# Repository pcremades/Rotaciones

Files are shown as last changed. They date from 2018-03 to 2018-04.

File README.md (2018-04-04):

# Sistema para Rotaciones
Sistema disñado para el estudio de dinámica de rotación de cuerpos rígidos. El sistema consiste en un soporte sobre el que se puede montar el objeto que se quiere poner a rotar.
El soporte giratorio tiene un sistema de adquisición de datos incorporado que registra la velocidad angular instantánea y la velocidad angular máxima registrada.

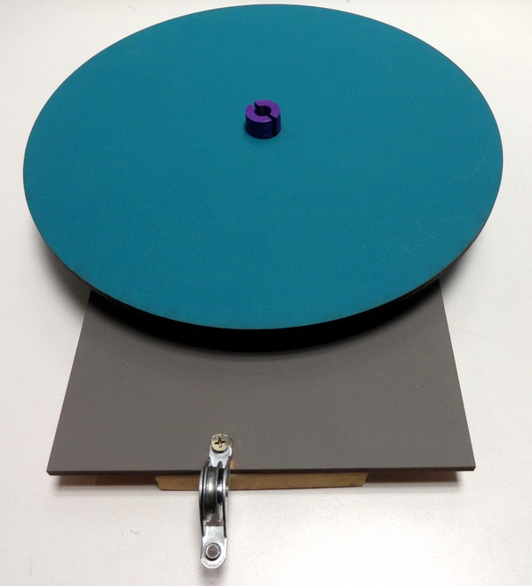
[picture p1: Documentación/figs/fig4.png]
Sistema de rotaciones con disco de 30cm


<br />Esta obra está bajo una <a rel="license" href="http://creativecommons.org/licenses/by-nc/4.0/">Licencia Creative Commons Atribución-NoComercial 4.0 Internacional</a>.

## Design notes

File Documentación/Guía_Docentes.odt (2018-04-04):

# Riel de Aire: guía para docentes

## Materiales

- Sistema para estudio de rotaciones con sistema de adquisición de datos
- Disco de madera de 30cm de diámetro
- PC
- Hilo
- Porta-pesas

## Armado

Coloque el sistema de rotaciones sobre la mesa, de manera tal que el extremo que tiene la polea quede fuera de la mesa.

Pase el hilo por cualquiera de los orificios practicados en el soporte plástico y fije con un trozo de cinta adhesiva la punta del mismo al soporte. El hilo deberá quedar enhebrado de forma tal que pueda enrollarse en la polea.

Pase el hilo por la roldana que se encuentra sobre el borde del equipo de rotaciones de modo que éste quede colgando. Ate el porta-pesas en ese extremo.

Coloque el disco de madera sobre el soporte y agregue peso al porta-pesas (aproximadamente 30g).

Verifique que el hilo se enrolle fácilmente en la polea al girar el disco, y que el peso adicionado sea suficiente para poner la rueda en movimiento una vez que se lo libera.

## Desarrollo

Dibuje para los estudiantes un esquema del sistema a analizar como el que se muestra en la figura 1.

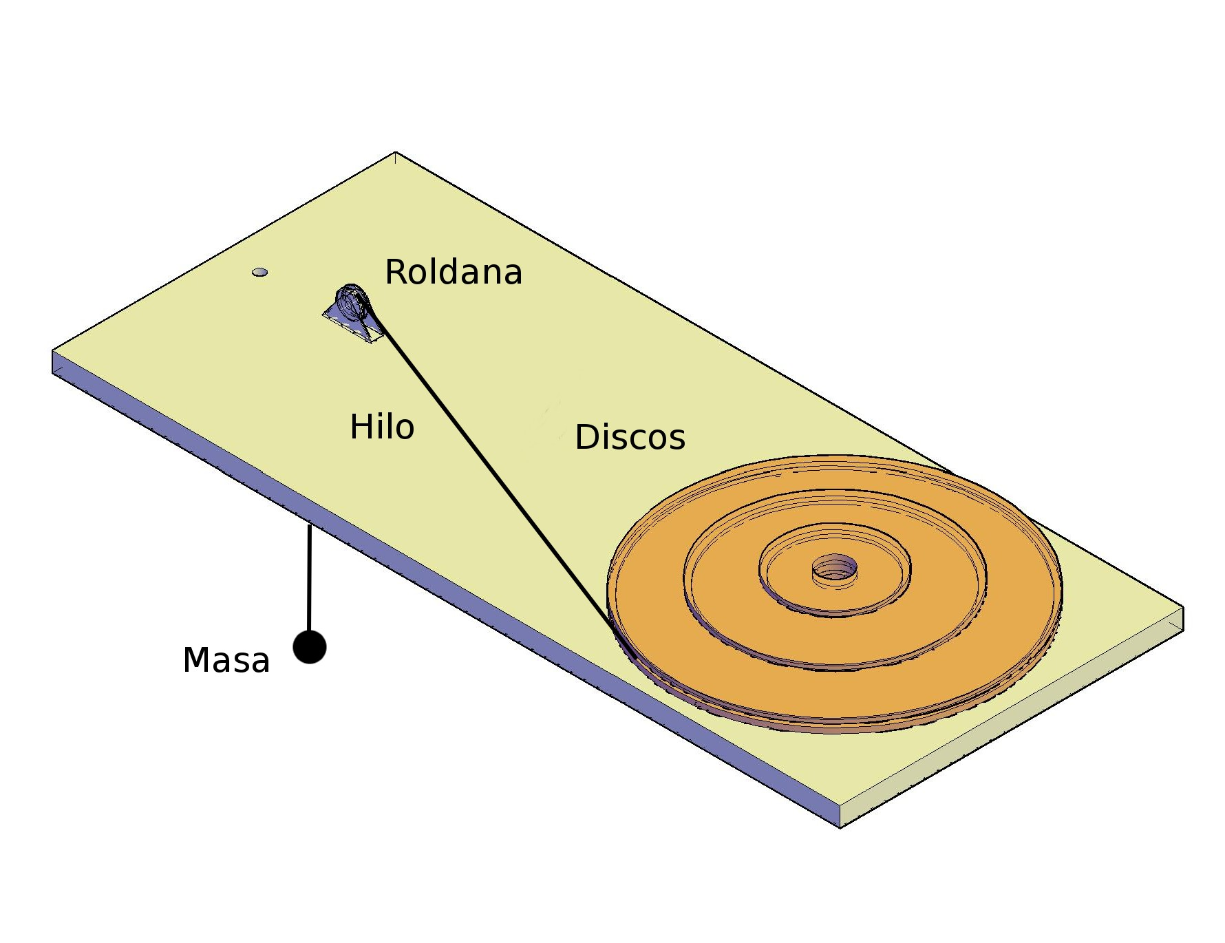
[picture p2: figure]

Fig. 1. Esquema del sistema bajo estudio.

Pida a los estudiantes que encuentren una expresión para la velocidad angular máxima del disco cuando el contrapeso (masa m) ha caído una altura h. Podrán hacer un análisis dinámico o plantear conservación de la energía mecánica. En el caso de hacer el análisis mediante consideraciones dinámicas, pida a los estudiantes que realicen el diagrama de cuerpo libre de los dos cuerpos. La expresión para la velocidad final está dada por la ecuación 1.

%omega_f = sqrt{ {2.(m.g . h - %tau_r. h over r)} over {I + m.r^2} }
(1)

donde I es el momento de inercia del disco, r es el radio de la polea sobre la que se enrolla el hilo, y τr es el torque de rozamiento, dado por el fabricante según la siguiente expresión:

τ=0.5*%mu*P*d (2)

donde:

τ : momento de fricción

μ : coeficiente de fricción constante del rodamiento: 0.002

P : carga dinámica equivalente: P=0.1*C

C : capacidad de carga del rodamiento: 2.6kN

d : diámetro interno del rodamiento: 8mm

Luego deberán medir las masas y la altura h para calcular la velocidad angular final. Además deberán calcular el intervalo de confianza de la velocidad final teórica mediante propagación de errores (ecuación 3):

%DELTA %omega_f = sqrt{ sum { left ( {partial %omega_f} over {partial x_i} right )^2 . %DELTA x_i^2 } } = sqrt{ left ( {partial %omega_f} over {partial m} . %DELTA m right)^2 +
left ( {partial %omega_f} over {partial I} . %DELTA I right)^2 +
left ( {partial %omega_f} over {partial h} . %DELTA h right)^2}
(3)

donde los errores estarán dados por los instrumentos utilizados para determinar m y h. En el caso del momento de inercia del disco, ésta es una medida indirecta, por lo que su incertidumbre debe determinarse también mediante propagación de errores a partir de los errores en la masa del disco y el radio.

Una vez establecido el intervalo de confianza de la estimación de ωf, deberán hacer el experimento y hallar el valor experimental de la velocidad angular final. Deberán realizar varias repeticiones del experimento y encontrar el valor medio y la desviación estándar y comparar los intervalos de confianza teórico y experimental y concluir.

El sistema de adquisición de datos registra la velocidad angular instantánea y la velocidad angular máxima.

## Sugerencias

Muestre a los estudiantes que la velocidad angular máxima no depende de la polea que elijan, siempre que la masa y la longitud del hilo sea la misma. Demuestre realizando el análisis a partir de la conservación de la energía mecánica.

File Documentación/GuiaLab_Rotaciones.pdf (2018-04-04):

### Laboratorio 5

### Rotación de cuerpos rígidos

Objetivo
Comprobar la validez de la ecuación:
EMi + WNC = EMf | (Ec.1)
en un sistema de cuerpos rígidos en rotación.
Donde,
EMi : Es la Energía Mecánica inicial del sistema,
WNC : Es el trabajo hecho por Fuerzas No Conservativas sobre el sistema, y
EMf : Es la Energía Mecánica final del sistema,

Materiales y métodos
El equipo consiste en un soporte rotativo con bajo rozamiento, pero no despreciable, y con sistema de adquisición de datos incorporado (Figura 1). Sobre el soporte se pueden montar discos o barras rígidas.
El soporte tiene 2 poleas con distintos diámetros. Se conecta mediante un hilo cualquiera de las poleas del soporte a una masa que cuelga de una roldana. De esta manera la tensión del hilo ejerce un torque sobre el sistema de discos que le imprimirá una aceleración angular.
Cuando el sistema se libera del reposo la masa suspendida comenzará a descender recorriendo una distancia conocida hasta que finalmente llega al extremo inferior del recorrido.
El equipo incluye un sistema de adquisición de datos que permite medir la velocidad angular instantánea de los discos y registra la velocidad angular máxima alcanzada.

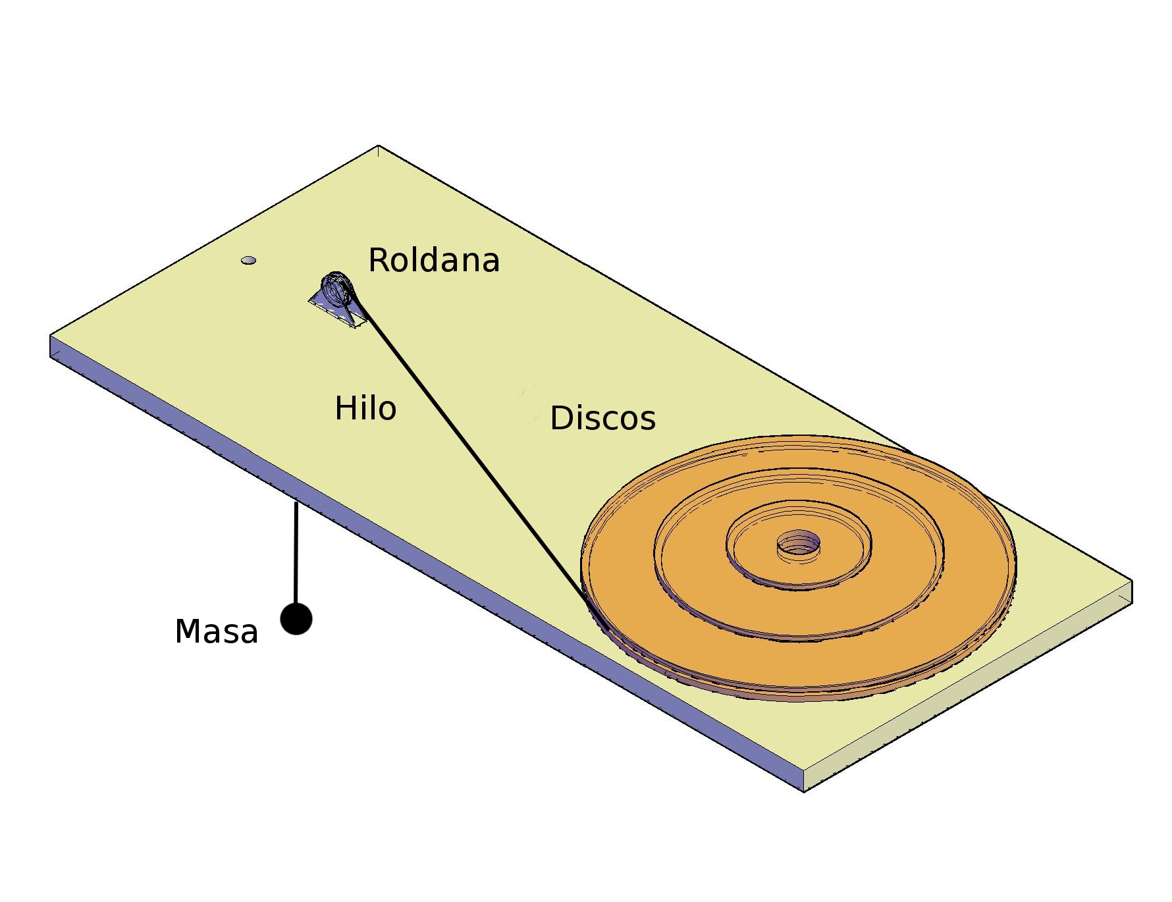
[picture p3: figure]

Figura 1: esquema del sistema de rotaciones.

Descripción de la experiencia

Deberá predecir la velocidad angular que alcanza el sistema de discos luego de que el torque de la tensión ha actuado sobre él hasta el momento en que la masa llega a la posición final.

Consideraciones sobre el Torque de la fricción:
Dado que no es posible despreciar la fricción en el eje del sistema de discos, deberá incluir el trabajo que hace esta fuerza de fricción en su análisis. Para ello, el fabricante del rodamiento proporciona toda la información necesaria. El torque de fricción viene determinado por la expresión:

τ=0.5∗μ∗P∗d
donde:
τ : momento de fricción
μ : coeficiente de fricción constante del rodamiento: 0.0013 P : carga dinámica equivalente: P=0.1∗C
C : capacidad de carga del rodamiento: 10kN
d : diámetro interno del rodamiento: 10mm

Consideraciones sobre el momento de Inercia:
Necesitará determinar una expresión para el momento de Inercia del cuerpo rígido que coloque en el soporte. Para ello, debe considerar la masa del soporte también.
1) A partir de la Ec. 1 encuentre una expresión para la velocidad angular máxima que alcanzará el sistema de discos y determine las variables que intervienen.
2) Mida en forma directa las variables que intervienen en su medición indirecta de la velocidad angular máxima.
3) Calcule la velocidad angular máxima que alcanzará el sistema.
4) Mida la velocidad angular máxima del sistema con la PC.
5) Calcule el intervalo de confianza de la predicción mediante teoría de propagación de errores.
6) Estime cuán significativo es el efecto del rozamiento.
7) Determine el intervalo de confianza de las medición que hizo de la velocidad angular máxima.
8) Compare ambas mediciones y concluya si son coincidentes.

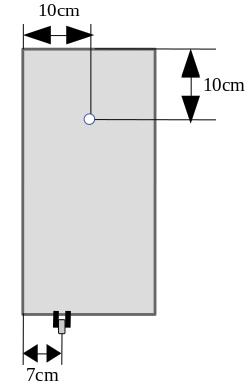
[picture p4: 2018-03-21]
Imagenes/fig1.jpg

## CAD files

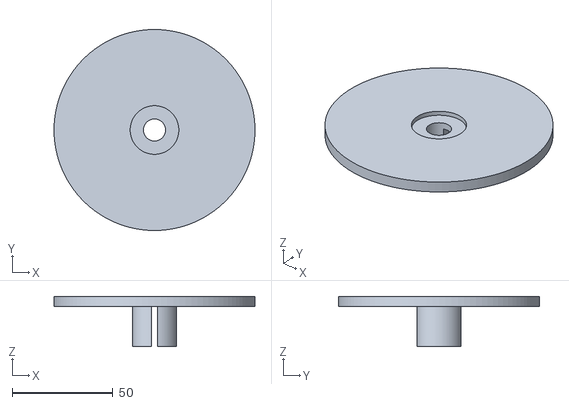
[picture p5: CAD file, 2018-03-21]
Hardware/plataforma rotacion.stl
100.0 x 100.0 x 25.0

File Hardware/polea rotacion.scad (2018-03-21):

include<UGroovePulley.scad>
$fn=100;

rotate([180,0,0])
translate([0,0,5])
//render_part(1);
render_part(2);

module render_part(part_to_render) {
	if (part_to_render == 1) poleas();
	if (part_to_render == 2) plataforma();
}

module poleas(){

//GroovePulley(radius, outer_radius, thickness, groove_radius, circles)
UGroovePulley(12.5,40,5,1,0);
translate([0,0,5])
UGroovePulley(12.5,20,5,1,0);
}

module plataforma(){
translate([0,0,-5])
difference(){
//Disco plataforma
cylinder(5,50,50);
//Encastre para ruleman axial
cylinder(2,12.1,12.1);    
//Eje
cylinder(21,5.5,5.5);   

}
difference(){
    cylinder(20,11,11);
    cylinder(21,5.5,5.5);
    // Ranura
translate([0,-20,0])    #cube([3,40,40]);
    
 }}

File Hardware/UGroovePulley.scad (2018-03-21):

// -------- This module was created by Min T Lin	--------
// -------- on the 31/01/2014 and is available 		--------
// -------- for distribution without any 				--------
// -------- restrictions. 										--------


$fn=100;		// render resolution 100 works well for a nice and smooth surface

// Bearing dimensions
//radius=7.5;	// 2.7mm works well for a 5mm drive shaft
//outer_radius=20;
//thickness=5;
//groove_radius=1;
//circles=0;
//UGroovePulley(11,40,5,1,0);
//translate([0,0,5])
//UGroovePulley(11,20,5,1,0);

module UGroovePulley(radius, outer_radius, thickness, groove_radius, circles)
{difference()
    {
	difference()
	{
		// main body
		cylinder(r= outer_radius, h=thickness);
		
		// shaft cutout
		cylinder(r=radius, h=thickness);
	
		// groove
		translate([0, 0, thickness/2])
			rotate_extrude(convexity = 10)
				translate([outer_radius, 0,0])
					circle(r=groove_radius);
		
	}
    
    for(i=[0:circles-1])	
				rotate([0,0,i*360/circles])
				translate([(radius+(outer_radius-radius)/2),0,-1])
				cylinder(r=thickness/2,h=max(thickness)+3);
}
}

// run the module
//UGroovePulley();

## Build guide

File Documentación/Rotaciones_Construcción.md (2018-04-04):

# Sistema para estudio de rotaciones

Este equipo está diseñado para realizar experimentos de rotaciones de cuerpos rígidos, conservación del momento angular y energía mecánica de rotación.

## Materiales

* Rodamiento axial URB 51100 (Diámetro interno 10mm; diámetro externo 24mm).

* Tornillo de 10mm con tuerca y arandelas.

* MDF o madera de 3mm de espesor (80cm x 30 cm aproximadamente).

* 100 gr. de ABS aproximadamente.

* Roldana con bajo rozamiento.

## Construcción

Cortar una placa rectangular de MDF de 30cm por 20cm que servirá de base para el equipo. Practicar un orificio de 10mm de diámetro como indica la figura 1.

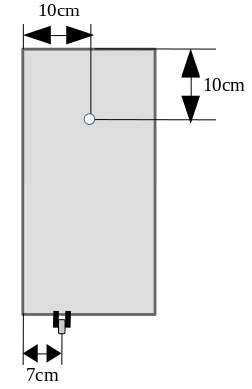
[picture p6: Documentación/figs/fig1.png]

*Fig 1. Esquema vista superior de la base del sistema de rotaciones.*

En el extremo opuesto al que se hizo el orificio, fijar la roldana ligeramente descentrada (6cm – 8cm).

Colocar el tornillo con la tuerca y las arandelas necesarias en el orificio. Colocar el rodamiento axial en el tornillo. Colocar el sistema de poleas en el eje (ver sistema de poleas).

## Sistema de poleas

En el repositorio podrá encontrar los archivos necesarios para imprimir en 3D el sistema de poleas. El mismo consiste en 2 partes que deben adherirse mediante cemento de contacto u otro pegamento adecuado para ABS. Antes, deberá adherir una de las coronas del rodamiento axial (la de mayor diámetro interno) al soporte y luego pegar las poleas al mismo. En la figura 2 puede verse el sistema de poleas armado y el rodamiento axial montado sobre el eje (tornillo de 10mm).

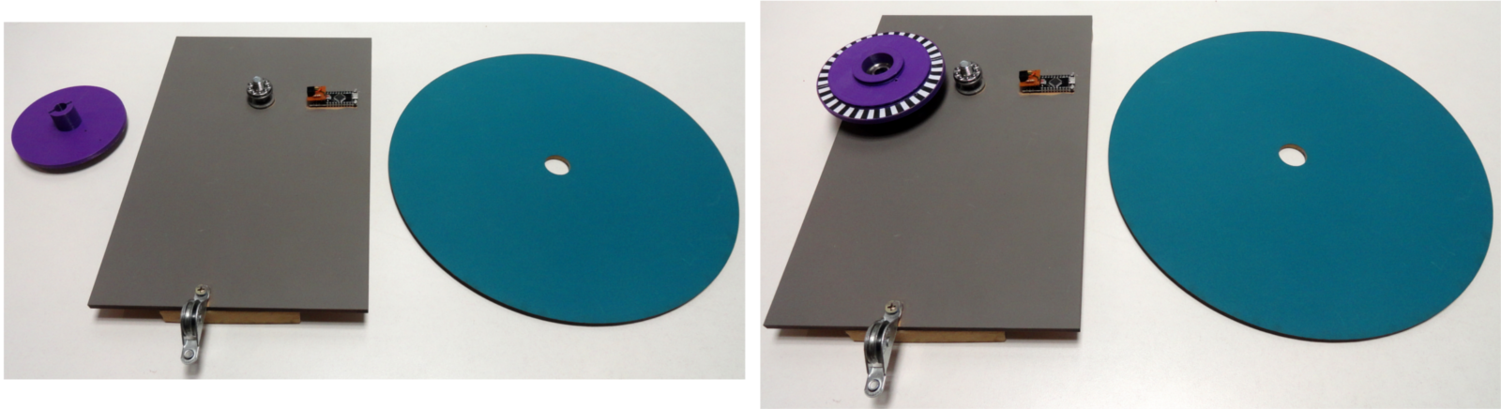
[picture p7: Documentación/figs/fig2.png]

*Fig 2. Foto del sistema de rotaciones completo.*

Por la parte inferior del sistema de poleas, debe pegar la zebra para el sistema de adquisición de datos. En el repositorio podrá encontrar el archivo para imprimir la zebra.

## Sistema de adquisición de datos

El sistema de adquisición de datos consiste en un sensor de luz por reflectancia tipo CNY70, conectado a un Arduino Nano. El sensor puede montarse directamente sobre el Arduino. El detalle sobre cómo conectar el sensor CNY70 puede encontrase [aquí](https://www.minitronica.com/uso-del-sensor-cny70-con-arduino/). Finalmente, la placa se fija sobre la base del sistema de rotaciones, procurando que el sensor quede alineado con la zebra del sistema de poleas.

## Accesorios

Con el MDF restante, cortar un círculo de 30cm de diámetro y otro de 20cm de diámetro con un orificio en el centro de 2,2cm. Se recomienda utilizar una cortadora láser para esta tarea. Estos discos se colocarán sobre el soporte para estudiar cinemática y dinámica de las rotaciones de estos cuerpos.

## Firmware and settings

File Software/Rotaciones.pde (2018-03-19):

/*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
    You should have received a copy of the GNU General Public License
    along with this program.  If not, see <http://www.gnu.org/licenses/>.
*/
/**************************************************************************************
* Autor: Pablo Cremades
* Fecha: 3/11/2015
* e-mail: pcremades@fcen.uncu.edu.ar.
* Descripción: Sistema de adquisición de datos de la rueda. Calcula la velocidad angular.
*  Determina la velocidad angular máxima. Determina el coeficiente de amortiguamiento
*  lineal.
*
* Uso:
*  - Conecte el sistema de adquisición de la rueda. Presione 'r' para reiniciar.
* Change Log:
* 
* To do:
*
*/

import processing.serial.*;

Serial port;
int ps, ps_old;
float ws, vs, g, ws1, maxWS, Tau;
float[] wsArray;
int iWS=0;
int nWS;
float theta;
float time=1, time1, diffTime;
char inByte;
int pulse1;
float radio=100;
int lookformin;

String[] serialPorts;


void setup(){
  size(800, 600);
  //noLoop();
  serialPorts = Serial.list(); //Get the list of tty interfaces
  for( int i=0; i<serialPorts.length; i++){ //Search for ttyACM*
    if( serialPorts[i].contains("ttyUSB") ){  //If found, try to open port.
                println(serialPorts[i]);
      try{
        port = new Serial(this, serialPorts[i], 115200);
        port.bufferUntil('\r');
      }
      catch(Exception e){
      }
    }
  }
  frameRate(30);
  ellipseMode(RADIUS);
  wsArray = new float[nWS];
}

//ISR para procesar datos del puerto serie.
void serialEvent( Serial port ){
    ps_old = ps;
    while(port.available() > 0){
    inByte = port.readChar();
    if( inByte == '2' || inByte == '1' ){  //Si se recibe un '2' o '1', incrementar la posición en 1. Esta previsto poder detectar sentido de giro.
      ps++;
      ws1= 2.0*PI/64.0/(millis() - time1)*1000.0;  //Calcula la velocidad angular instantánea.
      /*wsArray[iWS] = ws1;
      iWS++;
      if(iWS > 9)
        iWS=0;*/
      time1 = millis();
    }
 }
 //diffTime = millis() - time1;
}


void draw(){
  background(200);
  theta = ps*2*PI/168.0; // Posición en radianes
  translate(width/2, height/2);
  fill(0, 200, 255);
  ellipse(0,0, radio, radio);
  line(0,0, radio*cos(theta), radio*sin(theta));
  
  //Presinar 'r' para reiniciar.
  if( keyPressed ){
    if( key == 'r' ) 
      ps = 0;
      maxWS = 0;
  }
  
  //Imprime serie de datos cada 300ms
  if( millis() - time > 500.0 ){
    ws = 2*PI*((ps - pulse1)/168.0)/(millis() - time)*1000.0;  //Velocidad angular media cada 300ms
    /*for( int k=0; k<nWS; k++){
     ws = ws + wsArray[k];
    }*/
    //ws=;
    time = millis();
    pulse1 = ps;
    vs = ws * 0.15;  //Velocidad tangencial.
    /*print(time);
    print(" ");
    print(ps);
    print(" ");
    println(ws1);*/
  }
  
  //Busca la velocidad angular máxima
  if( ws > maxWS*1.1 ){
   maxWS = ws;
   Tau = millis();
   lookformin = 1;
  }
  //Calcula el coeficiente de amortiguamiento cuando la velocidad angular
  //ha caído a 0.1 rad/s.
  else if( (ws < 0.1) && (lookformin == 1) ){
   Tau = -maxWS/(millis() - Tau)*1000;
   lookformin = 0;
  }
    
  fill(150,20,20);
  textSize(24);
  text("Velocidad Angular = "+round(ws*100)/100.0, -width/2 + 30, -height/2 + 30);
  //text(ws, -100, -100);
  text("Máxima Velocidad Angular = "+round(maxWS*100)/100.0, -width/2 + 30, -height/2 + 70);
  //text(maxWS, -50, 150);
  //text("Alfa = "+round(Tau*100)/100.0, -width/2 + 30, -height/2 + 110);
  //text(Tau, -190, 170);
  textSize(14);
  fill(250,20,20);
  text("Presione 'R' para reiniciar", -width/2 + 30, height/2-20);
}

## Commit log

2018-03-19 Cambio la dirección de las imágenes
2018-03-19 Caption de la imagen 1 modificado
2018-03-19 Cambio estilo html a markdown de la figura 1
2018-03-20 agrego diseños openscad
    [UGroovePulley.scad, plataforma rotacion.stl, polea rotacion.scad]
2018-03-21 Updated via the Open Science Framework
2018-03-22 Corrigo el .gitignore
2018-03-23 Borro la Licencia de Rotaciones
2018-04-04 Reemplazo este repo con el ocontenido de Fisica_1/Rotaciones que es más actual
2018-04-04 Cambio el nombre del documento con instrucciones de ensamblado
2018-04-04 Agrego guía para docentes
2018-04-10 Cambio tamaño de la figura 2
2018-04-14 reordeno carpeta para que quede uniforme con el resto

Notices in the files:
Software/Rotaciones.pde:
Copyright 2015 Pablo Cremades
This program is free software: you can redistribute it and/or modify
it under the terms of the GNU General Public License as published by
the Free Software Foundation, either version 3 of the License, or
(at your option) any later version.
